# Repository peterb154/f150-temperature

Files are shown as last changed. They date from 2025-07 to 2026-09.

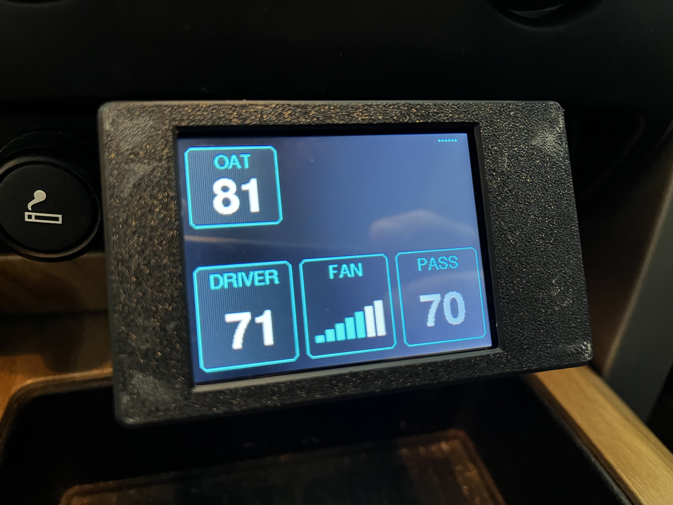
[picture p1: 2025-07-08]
docs/IMG_2838.HEIC.jpg

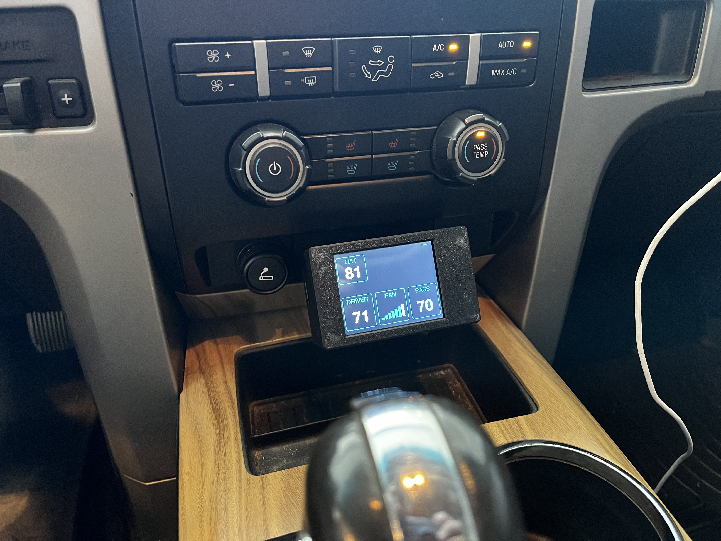
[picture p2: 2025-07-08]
docs/IMG_2837.HEIC.jpg

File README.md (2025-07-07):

# Ford F150 Temperature Display System

A production-ready Ford F150 temperature display system using ESP32-S3 with CAN bus integration and TFT display. This project provides a clean, automotive-grade interface showing outside air temperature, HVAC driver/passenger temperature settings, and fan speed with pixel-perfect text centering and professional styling.

## 🚗 Project Overview

This system captures and displays real-time Ford F150 climate control data via CAN bus at 125 kbps. It features a modern 4-card layout optimized for readability and includes special handling for HVAC off states, simulation mode for testing, and optional CSV logging for data analysis.

### Key Features

- **Real-time Temperature Display** - OAT, driver/passenger HVAC temps, and fan speed
- **Professional UI** - 4-card layout with pixel-perfect text centering and TrueType fonts
- **HVAC State Handling** - Blank display for disabled/off climate controls
- **Simulation Mode** - Built-in test mode cycling through various temperature scenarios
- **Adaptive Backlight** - PWM brightness control based on console dimming level
- **Optional CSV Logging** - Data capture for serial visualization tools (toggleable)
- **Parameterized Design** - Easy customization of fonts, colors, and layout

## 📁 Project Structure

```text
.
├── src/
│   ├── main.cpp                  # Production temperature display system
│   └── main.cpp.save.logger      # Original CAN logger (backup)
├── include/
│   ├── pins.h                    # Hardware pin assignments
│   └── colors.h                  # TFT display color definitions
├── can_visual_grid.py            # Python visualization tool (legacy)
├── F150_*.md                     # Decoded system documentation
│   ├── F150_CONSOLE_LIGHTS.md
│   ├── F150_HVAC_FAN.md
│   ├── F150_HVAC_TEMP.md
│   └── F150_OAT.md
├── platformio.ini                # ESP32 build configuration
├── pyproject.toml               # Python dependencies (for analysis tools)
└── README.md                    # This documentation
```

## 🔧 Hardware Requirements

### ESP32 Temperature Display Setup

- **ESP32-S3 Development Board** (320KB RAM, 8MB Flash recommended)
- **CAN Transceiver Module** (WCMCU-230 or MCP2551)
- **ILI9341 TFT Display** (320x240, SPI interface)
- **XPT2046 Touch Controller** (optional, for future expansion)

### Pin Configuration

Pin assignments are defined in `include/pins.h`:

```cpp
// CAN Bus pins
#define CAN_TX_PIN 47
#define CAN_RX_PIN 48

// ILI9341 Display pins
#define TFT_CS   45
#define TFT_RST  0
#define TFT_DC   35
#define TFT_MOSI 36
#define TFT_CLK  37
#define TFT_LED  38  // Backlight control
#define TFT_MISO 39

// Touch Controller pins (XPT2046)
#define TOUCH_CLK  40
#define TOUCH_CS   41
#define TOUCH_DIN  42
#define TOUCH_DO   2
#define TOUCH_IRQ  1

// Status LED
#define STATUS_LED_PIN 15
```

### Vehicle Connection

- **CAN High**: Connect to vehicle's CAN H line (used connection to car stereo)
- **CAN Low**: Connect to vehicle's CAN L line (used connection to car stereo)
- **Ground**: Connect to vehicle chassis ground
- **Power**: 12V from vehicle (with appropriate regulation to 3.3V/5V)

⚠️ **Important**: Use proper CAN bus termination and isolation, the MCU-230 has a built-in termination resistor. Always test on a non-critical vehicle first.

## 💻 Software Setup

### ESP32 Temperature Display Firmware

1. **Clone the repository** and navigate to the project directory
2. **Install PlatformIO** (if not already installed)
3. **Build and upload** the temperature display firmware:

    ```bash
    # Upload to ESP32-S3
    pio run --target upload

    # Monitor serial output (optional)
    pio device monitor
    ```

4. **Connect hardware** according to pin configuration above
5. **Power on** - the system will auto-start in simulation mode for testing
6. **Connect to vehicle CAN bus** to see live temperature data

### Main System Components

#### `src/main.cpp` - Temperature Display System

The main firmware provides a production-ready Ford F150 temperature display with:

- **4-Card Layout**: OAT (top-left), Driver Temp, Fan Speed, Passenger Temp (bottom row)
- **CAN Bus Integration**: Decodes Ford F150 PIDs at 125 kbps
  - `0x3C4` - Outside Air Temperature (bytes 6-7)
  - `0x3C8` - HVAC Driver/Passenger Temps (ASCII encoded, bytes 0-3)
  - `0x357` - Fan Speed (7 levels, byte 1)
  - `0x3B3` - Console Dim Level (PWM backlight control, byte 3)
- **Smart Display Logic**: Blank temperatures when HVAC is off/disabled
- **Adaptive Backlight**: PWM brightness based on console dimming
- **Simulation Mode**: Built-in test scenarios for development/demo

#### `include/pins.h` - Hardware Configuration

Centralized pin assignments for ESP32-S3 connections.

#### `include/colors.h` - Display Theme

Defines the professional color scheme using 16-bit RGB565 format:

- **COLOR_BACKGROUND** (`0x0841`) - Dark blue-grey background
- **COLOR_CARD_BG** (`0x2124`) - Lighter grey for temperature cards
- **COLOR_PRIMARY** (`0x07FF`) - Cyan accent color
- **COLOR_TEXT** (`0xFFFF`) - White text
- **COLOR_SUCCESS/WARNING/HOT** - Status and temperature-based colors

Colors can be easily customized by modifying the hex values in this file.

## 📊 System Features

### Temperature Display Layout

**4-Card Professional Interface:**
- **OAT Card** (top-left): Outside Air Temperature with "OAT" label
- **DRIVER Card** (bottom-left): Driver HVAC temperature setting
- **FAN Card** (bottom-center): Visual fan speed bars (7 levels)
- **PASS Card** (bottom-right): Passenger HVAC temperature setting

### Smart Display Features

- **Pixel-Perfect Centering**: All temperature values are precisely centered using TrueType fonts
- **Blank State Handling**: Cards show blank when HVAC is off or controls are disabled
- **Adaptive Backlight**: Display brightness automatically adjusts based on console dimming
- **Professional Styling**: Rounded cards, consistent spacing, automotive-grade appearance

### HVAC State Detection

- **HVAC Off**: When driver temp is 0x00,0x00, display shows blank and fan speed goes to 0
- **Passenger Disabled**: Passenger temp shows blank when controls are disabled
- **Normal Operation**: All temperatures display with clean numeric values (no "F" suffix)
- **Fan Visualization**: Horizontal bars indicate fan speed levels 0-7

### Simulation Mode

**Built-in Test Scenarios** (6-second cycles):
1. **Normal Operation** - All temps active, fan running
2. **HVAC System Off** - Driver blank, fan 0, passenger may be active
3. **Passenger Disabled** - Passenger blank, driver/fan normal
4. **All HVAC Off** - Both temps blank, fan 0
5. **Mixed States** - Various combinations for testing

### Optional CSV Logging

**Data Capture for Analysis:**
- **Toggle Control**: Set `enableCSVLogging = true` in code
- **CSV Format**: Timestamp, CAN ID, raw bytes, decoded temperatures
- **Serial Output**: Compatible with visualization tools
- **Performance**: Minimal overhead when enabled, zero when disabled

## 🔍 CAN Bus Analysis Tools

For reverse-engineering additional Ford F150 systems and analyzing CAN bus data, see the comprehensive analysis tools documentation:

**[CAN_ANALYSIS_README.md](CAN_ANALYSIS_README.md)**

Includes:
- Interactive CAN message visualization (`can_visual_grid.py`)
- Raw CAN logger firmware
- Complete reverse-engineering workflow
- Decoded system documentation
- Temperature calibration tools

## 🛠️ Usage

### Normal Operation

1. **Power On**: System starts automatically and shows simulation data
2. **Connect to Vehicle**: CAN bus connection switches to live data
3. **Display Updates**: Temperature cards update in real-time (10Hz refresh)
4. **Backlight Control**: Display brightness adapts to console dimming

### Configuration Options

**CSV Logging** (in `main.cpp`):

```cpp
bool enableCSVLogging = false;  // Set to true for data capture
```

**Simulation Mode** (forced during development):

```cpp
bool forceSimulation = true;   // Set to false for vehicle connection
```

### Hardware Customization

- **Pin Assignments**: Modify `include/pins.h` for different ESP32 boards
- **Display Colors**: Customize `include/colors.h` for different themes
- **Card Layout**: Adjust constants at top of `main.cpp` for sizing/positioning

## 🛠️ Troubleshooting

### Display Issues

**Blank or corrupted display:**

- Check SPI connections to ILI9341 (see `pins.h`)
- Verify power supply stability (3.3V/5V)
- Ensure correct pin definitions match your hardware

**No temperature updates:**

- Verify vehicle is running (systems sleep when off)
- Check CAN H/L connections and polarity
- Monitor serial output for CAN message reception
- Try simulation mode first (`forceSimulation = true`)

**Backlight not working:**

- Check TFT_LED pin connection (see `pins.h`)
- Verify PWM output is functioning
- Test with manual brightness setting

### Performance Issues

**Slow or flickering display:**

- Check power supply current capacity
- Verify SPI clock speed settings
- Monitor for memory issues in serial output

**CAN bus connection problems:**

- Ensure 125 kbps baud rate
- Verify CAN transceiver (MCU-230 recommended)
- Check termination resistance (120Ω)

### Development Tips

1. **Start with simulation mode** - validates display without vehicle
2. **Monitor serial output** - shows CAN status and decoded values
3. **Use CSV logging** - captures data for offline analysis
4. **Test incrementally** - verify each system (display, CAN, decoding) separately

## 🤝 License

MIT License

---

## Ready for your F150 dashboard! 🚗📊

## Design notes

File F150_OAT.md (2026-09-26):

# Ford F150 Outside Air Temperature Decoding

## 📍 CAN Message Location

- **PID**: `0x3C4`
- **Outside Air Temperature**: Bytes 6 & 7 (Big Endian)
- **Primary Byte**: Byte 6 (whole °C + 128)
- **Secondary Byte**: Byte 7, top 2 bits (quarter degrees C)

## 🌡️ Decoding Formula (Celsius Method)

```cpp
// 10-bit value: byte6 is whole degrees, top 2 bits of byte7 are quarters
int raw = (byte6 << 2) | (byte7 >> 6);
temperature_c = raw / 4.0 - 128;
temperature_f = (temperature_c * 1.8) + 32;
```

Example: `A1 B8` → raw 646 → 33.5°C → 92.3°F

## 🔬 Engineering Details

Encoding: Celsius-based with 128 decimal offset
Resolution: 0.25°C (byte6 + top 2 bits of byte7)
Range: -128°C to +127°C (-198°F to +261°F)
Practical Range: Covers all automotive conditions

## 📊 Tested Temperature Range

Tested: 34°F to 124°F (1°C to 51°C)
Accuracy: ±2-3°F average error

| Byte6 | Byte7 | Celsius | Fahrenheit | Notes |
|---|---|---|---|---|
| 0x83  | 0x38  | 3°C | 37°F | Cold |
| 0x91  | 0x78  | 17°C | 63°F | Mild |
| 0xA4  | 0x78  | 36°C | 97°F | Hot |
| 0xB1  | 0x38  | 49°C | 120°F | Very Hot |

## 🚗 Implementation Notes

Works for 2011+ F150 with outside air temperature display
Byte 6 is the primary temperature indicator
Formula follows Ford's automotive Celsius encoding standard
Update rate: Real-time with temperature changes

## 🔥 Engine Heat Damping

The raw sensor is accurate at speed but heat-soaks when slow or stopped
(captured: 87.3°F → 92.3°F in 10 s after stopping, actual 88°F). The truck
does not broadcast a filtered OAT, so the display damps it:

- **Above 20 mph for 30 s** (speed from `0x423`, see `F150_SPEED.md`): show the raw reading
- **Otherwise**: the display can only drop — engine heat only biases the sensor high
- **Boot**: the first reading is shown as-is (may read high if heat-soaked, like the factory dash)

## 🔒 Display Hysteresis

Damping stops the *value* drifting, but the shown whole degree still flickered at
speed: sensor resolution is 0.45°F, so a reading parked near a half-degree
boundary crossed it on one quantisation step and the display alternated between
two numbers (#7).

The displayed degree now carries a dead band — it only moves once the reading
clears it by `OAT_HYSTERESIS_F` (0.7°F), which is more than one sensor step:

```cpp
long displayedOAT(float raw, long shown, float hysteresis);  // include/oat_logic.h
```

Shown 72 changes to 73 at 72.7 and to 71 at 71.3, so real movement still tracks
while dither does not. Unit tested in `test/test_oat_logic/`.

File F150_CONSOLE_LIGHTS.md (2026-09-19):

# Ford F150 Console Lights Dimming Decoding

## 📍 CAN Message Location

- **PID**: `0x3B3`
- **Console Dimming**: Byte 3
- **Day/Night Mode**: Byte 0 (`0x00` = day, `0x04` = night)
- **Encoding**: One continuous brightness scale, `0x01`–`0x12` (1–18)

## 💡 Dimming Level Values

The dash light sensor switches between day and night mode. Each mode uses a
different slice of the same scale:

| Mode  | Byte0  | Byte2  | Byte3 (dimmer low → high) | Steps |
|---|---|---|---|---|
| Day | `0x00` | `0x05` | `0x0D` → `0x12` | 6 |
| Night | `0x04` | `0x04` | `0x01` → `0x0C` | 12 |

Example frames (captured 2026-09-18):

```text
day   full high: 00 43 05 12 00 00 00 38
day   full low:  00 43 05 0D 00 00 00 38
night full high: 04 83 04 0C 00 00 00 38
night full low:  04 83 04 01 00 00 00 38
```

Byte 1 toggles between `0x40`/`0x43` (day) and `0x80`/`0x83` (night); not used.

## 🧮 Decoding

```cpp
// Byte 3 is the brightness level directly; anything else is unknown
if (byte3 >= 0x01 && byte3 <= 0x12) {
    dim_level = byte3;  // 1-18
}
```

## 🚗 Implementation Notes

- Works for 2011+ F150 with console dimming controls
- Update rate: ~1 Hz, plus immediately on dimmer change
- Unknown values are ignored so the display keeps its last brightness
- Backlight PWM never drops below `MIN_BACKLIGHT_PWM` so the display is always readable
- Early versions only mapped the day range (`0x0D`–`0x12`), which blanked the display in night mode (#1)

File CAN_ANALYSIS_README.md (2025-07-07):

# 🔍 Ford F150 CAN Bus Analysis Tools

This directory contains tools for analyzing and reverse-engineering Ford F150 CAN bus messages. These tools complement the production temperature display system and are useful for discovering new PIDs and decoding protocols.

## 🛠️ Analysis Tools

### `can_visual_grid.py` - Interactive CAN Message Analyzer

A Python-based real-time CAN message visualization tool that displays messages in a grid format for pattern analysis and reverse engineering.

**Features:**
- **Real-time Display**: Live CAN message visualization with color-coded changes
- **Dual View Modes**: HEX (default) and ASCII modes for different analysis needs
- **Cell Selection**: Click up to 2 cells for detailed analysis and correlation
- **Temperature Calibration**: Built-in calibration mode for temperature sensor discovery
- **Pattern Detection**: Color coding highlights recent changes and printable ASCII

### `main.cpp.save.logger` - Raw CAN Logger

ESP32 firmware that captures raw CAN messages and outputs them via serial for analysis tools.

**Output Format:**
```
TIMESTAMP_MS,ELAPSED_MS,CAN_ID,LENGTH,BYTE0,BYTE1,BYTE2,BYTE3,BYTE4,BYTE5,BYTE6,BYTE7,EXTENDED
```

## 🎮 Using the Visual Grid Monitor

### Setup and Launch

1. **Upload Logger Firmware**:
   ```bash
   # Use the logger version (not the display system)
   cp src/main.cpp.save.logger src/main.cpp
   pio run --target upload
   pio device monitor  # Verify CAN messages are being received
   ```

2. **Install Python Dependencies**:
   ```bash
   pip install pygame numpy
   ```

3. **Launch Analysis Tool**:
   ```bash
   python can_visual_grid.py /dev/cu.wchusbserial56910252611
   # Replace with your ESP32's serial port
   ```

### Display Modes

- **HEX Mode**: Shows raw hexadecimal values (default)
- **ASCII Mode**: Shows ASCII characters, highlights printable text
- **Toggle**: Press `A` to switch between modes

### Cell Selection and Analysis

1. **Click cells** to select up to 2 for analysis
2. **Purple cell**: First selection
3. **Cyan cell**: Second selection
4. **Information panel**: Shows ASCII interpretation and temperature calculations

### Color Coding

- **Bright Green**: Recent changes (< 0.5 seconds)
- **Green**: Recent changes (< 1 second)
- **Yellow**: Somewhat recent (< 2 seconds)
- **Light Green**: Printable ASCII characters (ASCII mode only)
- **White**: No recent changes

### Temperature Calibration Mode

1. **Select temperature sensor cells** (e.g., PID 0x3C4, bytes 6&7)
2. **Press `T`** to enter calibration mode
3. **Adjust vehicle controls** and input actual LCD readings when prompted
4. **Press `T` again** to exit and calculate linear regression formula

### Keyboard Controls

- `A` - Toggle ASCII/HEX display mode
- `T` - Toggle temperature calibration mode
- `C` - Clear cell selection
- `↑↓` - Scroll through PIDs
- `ESC` - Exit application

Send `x` via serial console to insert markers for correlating data with specific actions (e.g., "start HVAC adjustment").

## 📊 Decoded Systems

This project has successfully reverse-engineered several F150 systems. Each system is documented in dedicated markdown files with complete decoding formulas:

- [F150_HVAC_TEMP.md](F150_HVAC_TEMP.md)
- [F150_HVAC_FAN.md](F150_HVAC_FAN.md)
- [F150_OAT.md](F150_OAT.md)
- [F150_CONSOLE_LIGHTS.md](F150_CONSOLE_LIGHTS.md)

## 🔧 Development Workflow

### 1. Data Capture Phase

```bash
# Start ESP32 logger
pio run -t upload

# Capture specific system in Python
python can_visual_grid.py /dev/ttyUSB0
```

### 2. ASCII Discovery Phase

- Switch to ASCII mode (`A` key)
- Look for green-highlighted printable characters
- Select suspicious byte pairs for analysis
- Ford often uses ASCII digits for human-readable values

### 3. Pattern Analysis

- Select 1-2 cells showing interesting patterns
- Use calibration mode for temperature sensors
- Correlate changes with vehicle control adjustments
- Document findings in new markdown files

### 4. Validation

- Test discovered formulas across temperature ranges
- Cross-reference with multiple data capture sessions
- Document edge cases and special states

### 5. Integration

- Add new decoders to the production temperature display system
- Update `main.cpp` with new PID handlers
- Test real-time display functionality

## 🚗 Known Ford F150 PIDs

### Temperature Systems
- **0x3C4** - Outside Air Temperature (bytes 6-7, Celsius + 40 offset)
- **0x3C8** - HVAC Driver/Passenger Temps (ASCII encoded, bytes 0-3)

### HVAC Controls  
- **0x357** - Fan Speed (7 levels, byte 1)
- **0x3B3** - Console Dim Level (PWM brightness, byte 3)

### Additional Systems

- Various engine, transmission, and body control PIDs documented in individual markdown files

## 💡 Analysis Tips

1. **Start with ASCII Mode**: Many Ford systems use human-readable ASCII encoding
2. **Look for Patterns**: Temperature values often follow predictable mathematical relationships
3. **Use Multiple Test Points**: Capture data across full range of values for accurate formulas
4. **Cross-Reference**: Compare findings with known automotive protocols and standards
5. **Document Everything**: Include test conditions, vehicle state, and environmental factors

## 🔄 Switching Back to Temperature Display

To return to the production temperature display system:

```bash
# Restore the display firmware
cp src/main.cpp.save.logger src/main.cpp.bak  # backup logger
git checkout src/main.cpp  # restore display system
pio run --target upload
```

The analysis tools and production display system are designed to work together - use the analysis tools to discover new data, then integrate findings into the display system for real-time monitoring.

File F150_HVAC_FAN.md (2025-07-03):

# Ford F150 HVAC Fan Speed Decoding

## 📍 CAN Message Location

- **PID**: `0x357`
- **Fan Speed**: Byte 3
- **Encoding**: Direct value mapping (7 discrete levels)

## 🌪️ Fan Speed Values

```cpp
// Direct byte value to fan speed mapping
switch(byte3) {
   case 0x1C: return "HIGH (Level 7)";
   case 0x18: return "Level 6";
   case 0x14: return "Level 5";
   case 0x10: return "Level 4";
   case 0x0C: return "Level 3";
   case 0x08: return "Level 2";
   case 0x04: return "LOW (Level 1)";
   default:   return "OFF or Unknown";
}
```

| Byte3 Value | Fan Level | Description |
|---|---|---|
| 0x1C | 7 | HIGH (Maximum airflow) |
| 0x18 | 6 | High-medium |
| 0x14 | 5 | Medium-high |
| 0x10 | 4 | Medium |
| 0x0C | 3 | Medium-low |
| 0x08 | 2 | Low-medium |
| 0x04 | 1 | LOW (Minimum airflow) |
| Other | 0 | OFF or Unknown |

## 🔬 Engineering Details

- Encoding: Simple descending 4-bit pattern
- Resolution: 7 discrete fan speeds
- Pattern: Each level decreases by 0x04 (4 decimal)
- Range: 0x04 to 0x1C (4 to 28 decimal)

## 🧮 Alternative Formula
```cpp// Calculate fan level from byte value
if (byte3 >= 0x04 && byte3 <= 0x1C && (byte3 % 4) == 0) {
    fan_level = (byte3 / 4);  // Results in 1-7
} else {
    fan_level = 0;  // OFF or invalid
}
```

## 🚗 Implementation Notes

Works for 2011+ F150 with manual or automatic HVAC controls
Update rate: Real-time with fan speed adjustment
Simple linear encoding makes this easy to decode
Pattern: Each fan level = previous level + 4

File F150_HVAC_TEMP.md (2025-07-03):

# Ford F150 HVAC Temperature Setpoint Decoding

## 📍 CAN Message Location

- **PID**: `0x3C8`
- **Driver Temperature**: Bytes 0 & 1
- **Passenger Temperature**: Bytes 2 & 3

## 🧮 Decoding Formula (ASCII Method)

```cpp
// Ford encodes position as ASCII decimal digits!
// Example: 0x37, 0x35 = ASCII "75" = position 75

// Convert bytes to ASCII characters
char tens_digit = (char)byte0;  // '6', '7', '8', '9'
char ones_digit = (char)byte1;  // '0' through '9'

// Build position string and convert to integer
char position_str[3] = {tens_digit, ones_digit, '\0'};
int position = atoi(position_str);  // "75" -> 75

// Map position to temperature
if (position == 60) {
    return "LOW";
} else if (position == 90) {
    return "HIGH"; 
} else if (position >= 65 && position <= 84) {
    int temp_f = position - 5;  // 65->60°F, 75->70°F, etc.
    return temp_f;
} else {
    return "UNKNOWN";
}
```

## 🔤 ASCII Encoding Details

- **Byte0 Range**: 0x36-0x39 = ASCII '6'-'9' (tens digit)
- **Byte1 Range**: 0x30-0x39 = ASCII '0'-'9' (ones digit)
- **Position Range**: "60" to "90" (ASCII decimal)
- **Ford's Logic**: Direct ASCII decimal encoding for easy diagnostics

## 📊 Temperature Ranges

- **LOW**: Position 60 (Below 60°F)
- **Normal Range**: 60-83°F (positions 65-84)
- **HIGH**: Position 90 (Above 83°F)
- **Resolution**: 1°F per step

## 🎯 Example Values

| Byte0 | Byte1 | ASCII | Position | Result |
|---|---|---|---|---|
| 0x36  | 0x30  | "60"  | 60 | LOW |
| 0x36  | 0x35  | "65"  | 65 | 60°F |
| 0x37  | 0x30  | "70"  | 70 | 65°F |
| 0x37  | 0x35  | "75"  | 75 | 70°F |
| 0x38  | 0x34  | "84"  | 84 | 79°F |
| 0x39  | 0x30  | "90"  | 90 | HIGH |

## 🚗 Implementation Notes

- Both driver and passenger use identical ASCII encoding
- Formula works for 2011+ F150 with dual-zone HVAC
- Update rate: Real-time with HVAC knob adjustments
- Celsius conversion: `temp_c = (temp_f - 32) * 5/9`
- **Key Insight**: Ford uses ASCII digits for human-readable diagnostics
- HVAC OFF: Driver temps will be zero (0x3C8 b0 = 0x00 & b1 = 0x00)
- PASS TEMP OFF: Pass temps will be zero (0x3C8 b2 = 0x00 & b3 = 0x00)
- LOW == 60°F
- HIGH == 85°F, then next click jumps to 90°F

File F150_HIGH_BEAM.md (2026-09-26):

# Ford F150 High Beam Decoding

## 📍 CAN Message Location

- **PID**: `0x3C3`
- **High Beam**: Byte 0, bit 1 (mask `0x02`)
- **Headlamps**: Byte 0, bits 7 / 4 — set together as `0x90` when lights are on

## 🧮 Decoding

```cpp
bool highBeamOn = (byte0 & 0x02) != 0;
```

## 📊 Observed Byte 0 Values (captured 2026-09-26)

| Byte0  | Headlamps | High beam |
|---|---|---|
| `0x00` | off | off |
| `0x02` | off | **on** |
| `0x90` | on | off |
| `0x92` | on | **on** |

Byte 1 bit 5 is the inverse of the same state (`0x21` → `0x01` on high beam) and is
not used.

## ✅ Verification

Two independent captures, analysed by diffing every byte of every ID:

- **Five toggles**: bit 1 went high at 14.9, 17.1, 18.8, 20.5 and 22.2 s — exactly
  five pulses, no other byte on the bus matched
- **Single flip, held**: bit 1 low until 10.8 s, then high for 72 s continuously

## 🚗 Implementation Notes

- Update rate: ~1 Hz, plus immediately on change (same pattern as `0x3B3`)
- **There is no separate flash-to-pass on this truck** — flashing is cycling the
  high beams, so it is the same bit by construction and cannot be distinguished
- Measured toggle durations were **1.0–1.7 s**, so the flood-arm delay must exceed
  that comfortably; `HIGH_BEAM_ARM_MS` is 2500 ms
- Treat a stale message as high beam **off**: if no `0x3C3` arrives for
  `HIGH_BEAM_STALE_MS`, drop the flood rather than holding the last state

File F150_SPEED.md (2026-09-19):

# Ford F150 Vehicle Speed Decoding

## 📍 CAN Message Location

- **PID**: `0x423`
- **Vehicle Speed**: Bytes 0 & 1 (Big Endian)

## 🧮 Decoding Formula

```cpp
int raw = (byte0 << 8) | byte1;
float kph = (raw - 10000) / 100.0;  // 0.01 km/h per bit, 10000 = stopped
float mph = kph / 1.609;
```

## 📊 Captured Values (2026-09-18)

| Raw | km/h | mph  | Notes |
|---|---|---|---|
| `10000` | 0 | 0 | Stopped |
| `13054` | 30.5 | 19.0 | Accelerating |
| `15070` | 50.7 | 31.5 | Holding an indicated 30 mph |

Reads ~5% above the speedometer; close enough for thresholds.

## 🚗 Implementation Notes

- Update rate: ~10 Hz
- Used to decide when the raw OAT reading can be trusted (see `F150_OAT.md`)

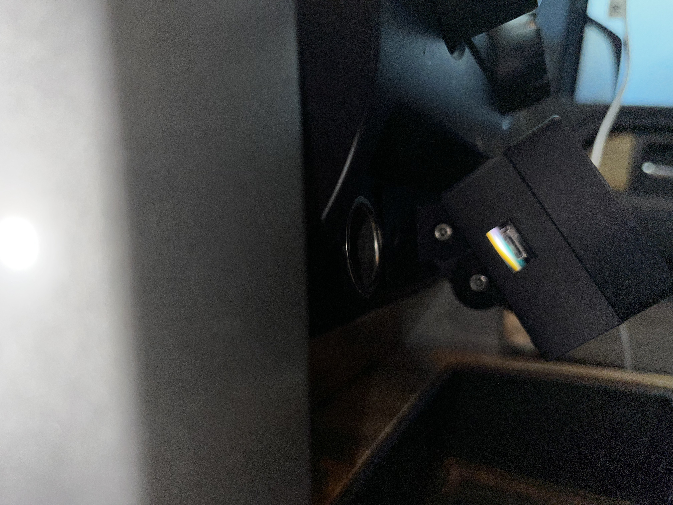
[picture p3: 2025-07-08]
docs/IMG_2835.HEIC.jpg

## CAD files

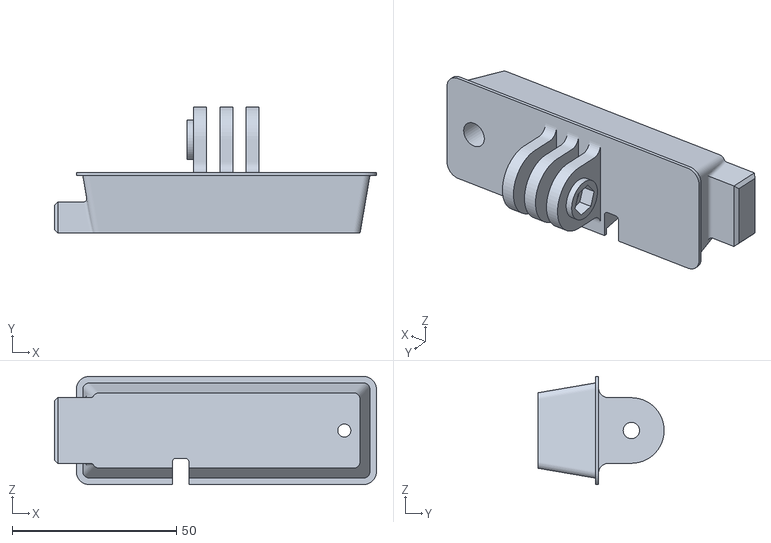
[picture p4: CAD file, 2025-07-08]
case/Truck_mount.stl
98.1 x 38.5 x 33.0

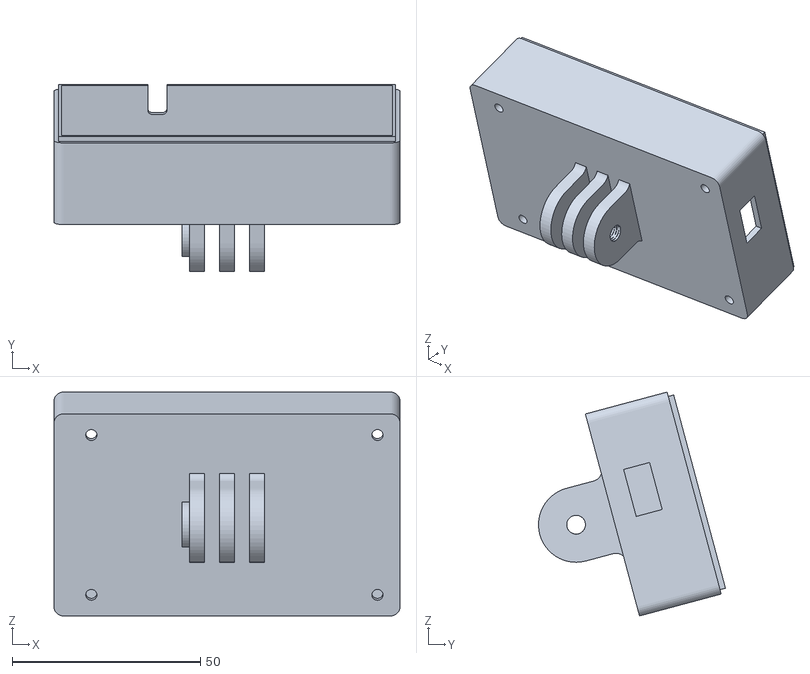
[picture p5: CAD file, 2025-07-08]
case/Screen_back.stl
92.0 x 49.7 x 59.5

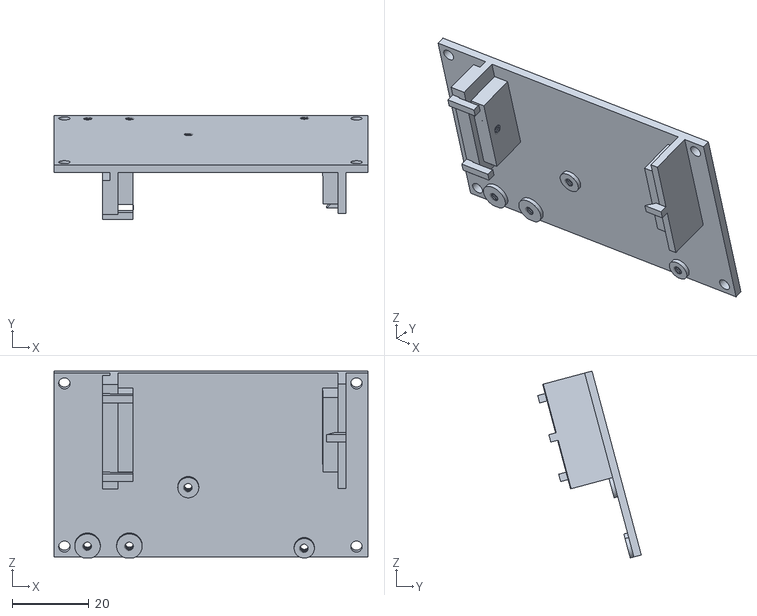
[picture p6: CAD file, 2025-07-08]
case/PartPlate.stl
81.8 x 27.0 x 48.7

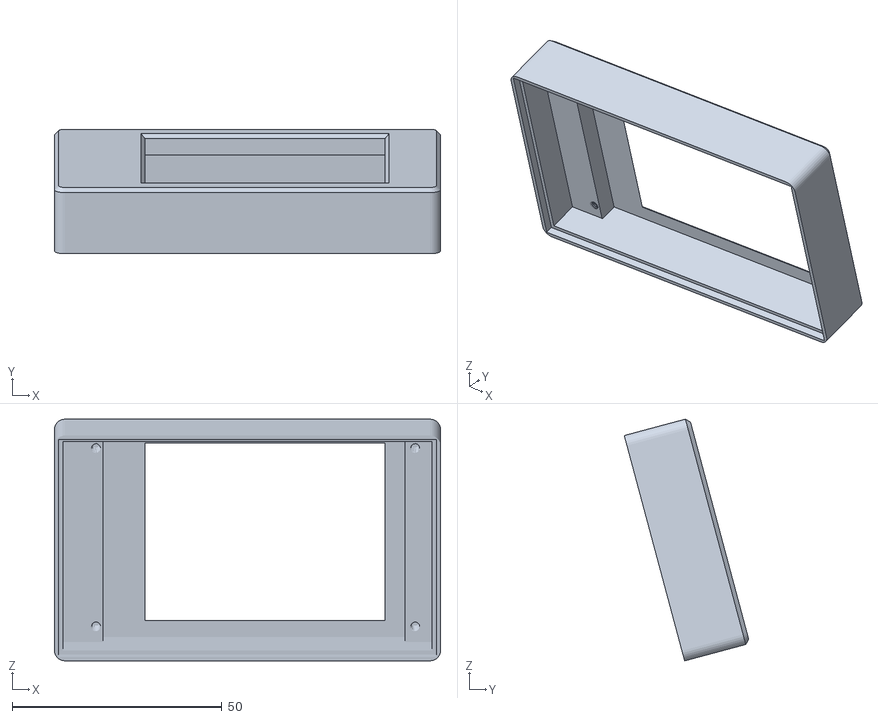
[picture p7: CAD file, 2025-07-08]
case/Screen_case.stl
92.0 x 29.7 x 57.6

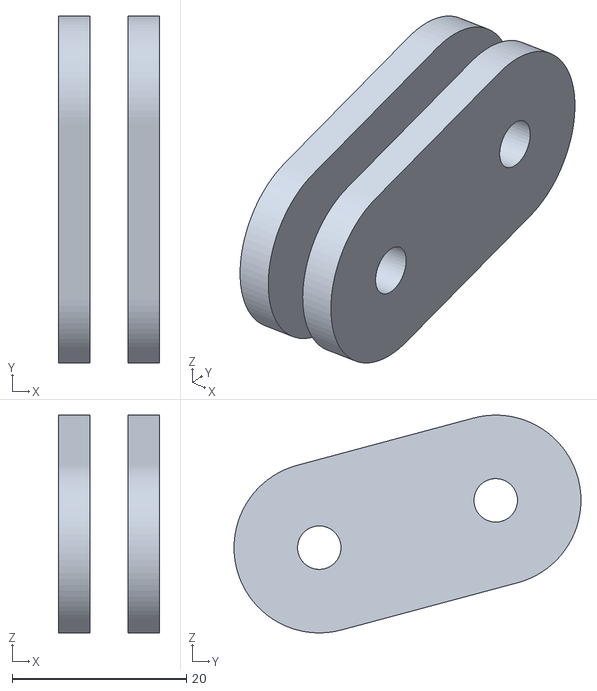
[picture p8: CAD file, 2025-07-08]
case/Arm.stl
11.6 x 39.9 x 25.0

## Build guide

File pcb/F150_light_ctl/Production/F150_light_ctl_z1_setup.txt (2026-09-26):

================================================================
Makera Z1 setup sheet -- F150_light_ctl
================================================================

G-code    F150_light_ctl_z1.ngc
Board     F150_light_ctl.kicad_pcb  (1.60mm thick)
Side      TOP-DOWN -- component side up.
Origin    KiCad drill/place (aux) origin
Extent    X -7.31 to 9.39, Y -11.85 to 3.35 mm
Depth     1.80mm  (1.60 board + 0.20 breakthrough)
Spindle   13000 rpm

TOOLS, in program order
----------------------------------------------------------------
  T1     0.80 mm  CORN/FISHTAIL END MILL     5 hole(s), every size with this one bit, milled helically
  T2     1.20 mm  CORN/FISHTAIL END MILL     outline 62.8mm, 1 path(s), 4 tab(s) of 1.00mm at Z-1.00

You will be asked to install:
----------------------------------------------------------------
  T1   0.80mm CORN/FISHTAIL END MILL (NOT a twist drill)
  T2   1.20mm CORN/FISHTAIL END MILL (NOT a twist drill)

BEFORE YOU START
----------------------------------------------------------------
  * USE A SACRIFICIAL LAYER. Cuts go ~0.2mm past the far face.
  * Install T1, then Tool dropdown -> Change tool -> T1
    (registers the tool and sets its TLO).
  * Set XY origin to the drill/place origin. Do not move it again.
  * Run the first tool with Auto Z Probe ON. Z0 is tool-independent,
    so later tools need no re-probe -- the M6 re-zeros them on the
    back-right setter.

DURING THE RUN
----------------------------------------------------------------
  * Each M6 stops and prompts for the swap, then re-zeros on the
    setter. Do not skip the re-zero.
  * The outline is cut LAST: it is what frees the part. It stays
    held by 4 tab(s) of 1.00mm until you snap them.

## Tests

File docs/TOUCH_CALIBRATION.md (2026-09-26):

# Touch Calibration

The XPT2046 reports raw 12-bit ADC values, not pixels. Mapping them to the
screen needs the raw value at each edge of the panel, stored as `TOUCH_CAL_*`
in `include/touch_logic.h`.

## Why this has its own procedure

Getting the range wrong is **invisible in the middle of the screen**. A linear
map with symmetric endpoint errors is still exactly right at the centre, so a
centre press proves nothing. The error only appears at the edges, where presses
clamp and silently miss whatever is there.

That is how #9 survived: `TOUCH_CAL_MAXY` was 2830 against a real 3402, so every
press on the top of the screen clamped to `sy = 0` and missed a button starting
at `y = 10`. It looked like unreliable touch hardware for an entire session.

**Measure the edges. Never extrapolate them.**

## Procedure

1. Flash the bring-up harness:

   ```bash
   pio run -e floodtest -t upload --upload-port /dev/cu.usbmodem*
   ```

2. Open a serial monitor at 115200 (`pio device monitor -e floodtest`).

3. Press firmly into **all four edges** of the glass, right at the bezel — top,
   bottom, left, right. Drag along each edge to be sure you reach the extremes.
   The harness tracks the running minimum and maximum as you go.

4. Send `c`. It prints the four constants ready to paste:

   ```
   #define TOUCH_CAL_MINX 780
   #define TOUCH_CAL_MAXX 3298
   #define TOUCH_CAL_MINY 858
   #define TOUCH_CAL_MAXY 3402
   ```

   Send `r` to start over if you want a clean run.

5. Paste them into `include/touch_logic.h`.

6. Run the host tests — they share those constants, so they will tell you if a
   known-good press no longer lands on the button:

   ```bash
   pio test -e native
   ```

7. Reflash the display firmware:

   ```bash
   pio run -e esp32s3 -t upload --upload-port /dev/cu.usbmodem*
   ```

## Notes

- Both axes run **opposite** to the display: a low raw value is the bottom/right
  of the screen, a high one is the top/left. `touch_logic.h` handles the
  inversion; the constants are plain observed minima and maxima.
- A finger has width, so pressing "the edge" lands slightly inside it. Erring a
  little wide is harmless — mapped values are clamped.
- The harness also toggles the flood relay (`1`, `0`, `p`), which is the only
  way to control the light bar if the touchscreen is unavailable.

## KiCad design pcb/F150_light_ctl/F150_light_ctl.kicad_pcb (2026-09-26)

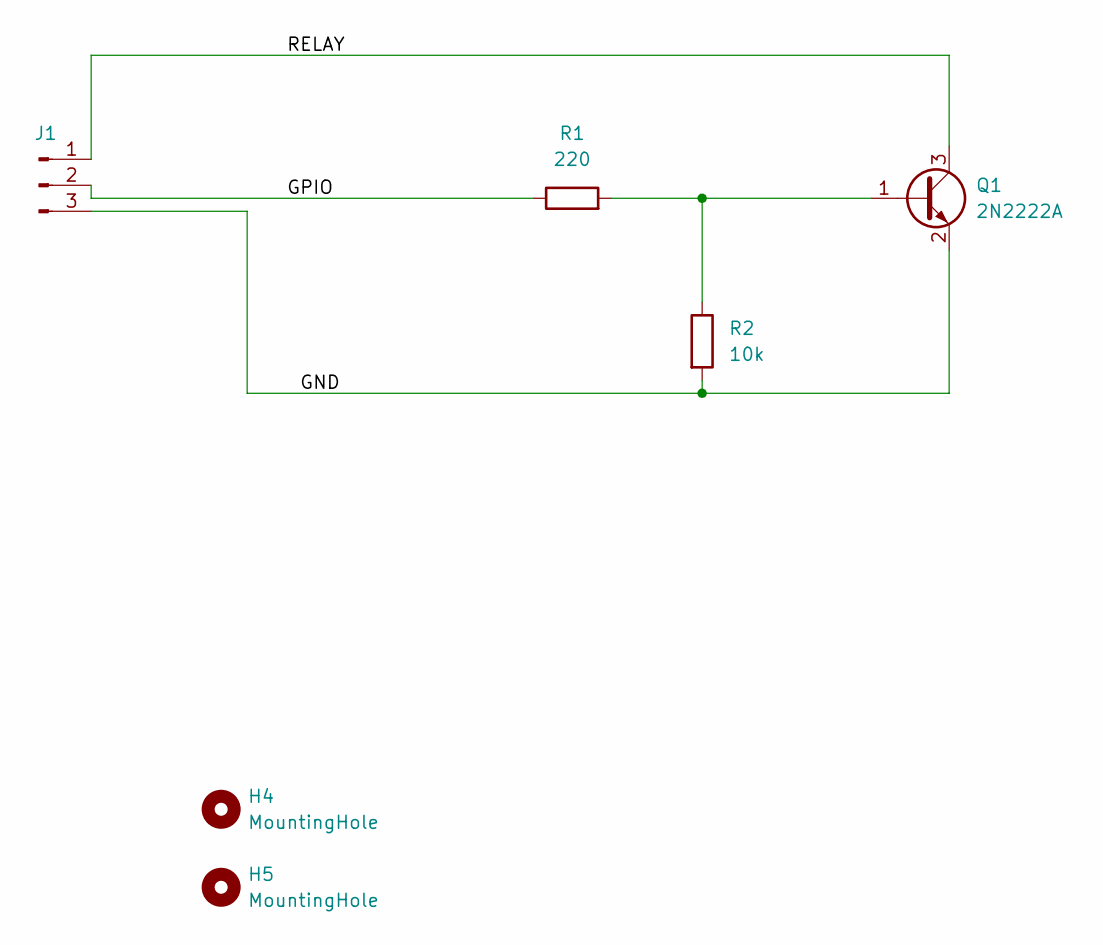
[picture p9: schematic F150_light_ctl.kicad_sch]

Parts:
H4, H5: MountingHole; MountingHole_3.5mm
J1: PinHeader_1x03_P2.54mm_Vertical
Q1: 2N2222A; SOT-23
R1: 220; R_0805_2012Metric
R2: 10k; R_0805_2012Metric

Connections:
/GND: J1.3, Q1.2 (E), R2.2
/GPIO: J1.2, R1.1
/RELAY: J1.1, Q1.3 (C)
unnamed: Q1.1 (B), R1.2, R2.1

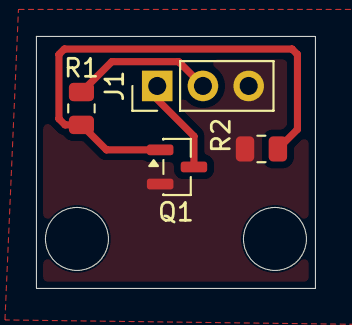
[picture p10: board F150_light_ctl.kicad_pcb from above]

Board: 2 copper layers, 15.5 x 14.0 mm, 6 parts (0 on the bottom side), 4 nets.

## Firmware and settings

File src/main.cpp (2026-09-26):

#include <Arduino.h>
#include <SPI.h>
#include <pins.h>
#include <colors.h>
#include <Adafruit_GFX.h>
#include <Adafruit_ILI9341.h>
#include <driver/twai.h>
#include <XPT2046_Touchscreen.h>
#include <Preferences.h>
#include <flood_logic.h>
#include <oat_logic.h>
#include <touch_logic.h>
#include <stdint.h>
#include <Fonts/FreeSans9pt7b.h>
#include <Fonts/FreeSansBold12pt7b.h>
#include <Fonts/FreeSansBold18pt7b.h>
#include <Fonts/FreeSansBold24pt7b.h>

// ========== LAYOUT PARAMETERS ==========
// Card dimensions and spacing
#define CARD_WIDTH 95
#define CARD_HEIGHT 100
#define CARD_RADIUS 6
#define CARD_SPACING 10

// OAT card (smaller, top-left)
#define OAT_WIDTH 90
#define OAT_HEIGHT 80
#define OAT_X 10
#define OAT_Y 10

// Bottom row cards
#define BOTTOM_Y 130
#define DRIVER_X 10
#define FAN_X (DRIVER_X + CARD_WIDTH + CARD_SPACING)
#define PASS_X (FAN_X + CARD_WIDTH + CARD_SPACING)

// Flood light button - top-right grid slot (OAT's row, PASS's column)
#define FLOOD_X PASS_X
#define FLOOD_Y OAT_Y
#define FLOOD_W OAT_WIDTH
#define FLOOD_H OAT_HEIGHT

// Touch calibration lives in include/touch_logic.h so the firmware and the
// host tests share one set of numbers. See docs/TOUCH_CALIBRATION.md to
// re-measure it.
#define TOUCH_HIT_MARGIN 8   // forgiveness around the button edge
#define TOUCH_DEBOUNCE_MS 250

// "OFF" is three wide glyphs; the 24pt value font overflows a 90px card
#define FLOOD_STATE_FONT &FreeSansBold18pt7b

// High beam arming. Measured stalk toggles ran 1.0-1.7 s, and this truck has no
// separate flash-to-pass, so the delay must outlast a flash or the bar strobes
// oncoming traffic. Turning off is immediate; only turning on waits.
#define HIGH_BEAM_MASK      0x02
#define HIGH_BEAM_ARM_MS    2500
#define HIGH_BEAM_STALE_MS  3000   // no 0x3C3 for this long -> assume beams off

// Font sizes
#define LABEL_FONT &FreeSans9pt7b
#define VALUE_FONT &FreeSansBold24pt7b  // Larger font
#define SMALL_FONT &FreeSansBold12pt7b

// Text positioning offsets
#define LABEL_OFFSET_X 10
#define LABEL_OFFSET_Y 20
#define VALUE_OFFSET_X 15
#define VALUE_OFFSET_Y 80  // Adjusted for larger font
#define OAT_VALUE_OFFSET_Y 65  // OAT card is shorter

// F150 CAN Message IDs based on documentation
#define PID_OAT           0x3C4  // Outside Air Temperature
#define PID_HVAC_TEMP     0x3C8  // HVAC Temperature Settings
#define PID_HVAC_FAN      0x357  // HVAC Fan Speed
#define PID_CONSOLE_LIGHTS 0x3B3 // Console Light Dimming
#define PID_VEHICLE_SPEED 0x423  // Vehicle Speed
#define PID_LIGHTING      0x3C3  // Headlamp / high beam (see F150_HIGH_BEAM.md)

// OAT damping: engine heat skews the sensor high when slow or stopped
#define OAT_MOVING_MPH    20     // Above this speed...
#define OAT_MOVING_MS     30000  // ...for this long, trust the raw OAT
// Dead band on the displayed degree. Larger than one 0.45 F sensor step, so
// quantisation noise near a boundary cannot flip the number (see #7).
#define OAT_HYSTERESIS_F  0.7f

// Console dim scale: night mode uses 1-12, day mode uses 13-18
#define NIGHT_MAX_LEVEL    12
#define MAX_DIM_LEVEL      18
#define MIN_BACKLIGHT_PWM  15  // Never fully dark, even at lowest night dimmer
#define NIGHT_MAX_PWM      170
#define DAY_MIN_PWM        60  // Day gets its own range so the dimmer is visible

// Create TFT instance
Adafruit_ILI9341 tft = Adafruit_ILI9341(TFT_CS, TFT_DC, TFT_MOSI, TFT_CLK, TFT_RST, TFT_MISO);
// Polled, not IRQ-driven. In IRQ mode the library sets isrWake=false as soon as
// one sample reads below its pressure threshold, and only a new falling edge
// rearms it - so a soft press is sampled once while the finger is still
// settling, discarded, and never looked at again. With no IRQ pin isrWake stays
// true and update() samples on every call.
//
// Note this was NOT the cause of the missed presses in #9 - that was a bad
// calibration range. The latch is a real defect regardless.
XPT2046_Touchscreen ts(TOUCH_CS);

// Flood light state. Mode is what the button selects; lit is what the pin does.
FloodMode floodMode = FLOOD_OFF;
FloodMode prevFloodMode = FLOOD_ARMED;  // mismatch forces the first draw
bool floodLit = false;
bool prevFloodLit = true;

bool highBeamOn = false;
unsigned long highBeamSince = 0;    // when the beams last came on
unsigned long lastLightingMsg = 0;  // for the stale-bus watchdog
Preferences floodPrefs;

// Display data variables
float outsideTemp = 72.0;     // Outside Air Temperature (°F), damped for display
bool oatSeeded = false;       // First OAT reading is shown as-is
unsigned long movingSince = 0; // millis() when speed went above OAT_MOVING_MPH, 0 = slow
int driverTempSet = 72;       // Driver temperature setting (°F)
int passengerTempSet = 70;    // Passenger temperature setting (°F)
int fanSpeed = 3;             // Fan speed level (0-7)
int consoleDimLevel = MAX_DIM_LEVEL; // Console brightness (1-18)
bool dataReceived = false;

// Previous values for dirty flag checking
long shownOAT = OAT_DISPLAY_UNSET;      // degrees we want on screen
long drawnOAT = OAT_DISPLAY_UNSET - 1;  // what is on screen; mismatch forces first draw
int prevDriverTempSet = -1;
int prevPassengerTempSet = -1;
int prevFanSpeed = -1;

// Display update tracking
unsigned long lastDisplayUpdate = 0;
unsigned long lastSimulationUpdate = 0;

// CSV Logging for serial visualization
// Set enableCSVLogging = true to output CSV data compatible with F150 serial visualizer
// This adds minimal performance overhead and is useful for data analysis
bool enableCSVLogging = false;  // Set to true to enable CSV output
unsigned long sessionStartTime = 0;
unsigned long messageCount = 0;
bool simulationMode = false; // Force simulation for testing

// Function prototypes
void setup();
void loop();
void initDisplay();
void initCAN();
void updateDisplay();
void simulateData();
void processCanMessages();
void drawTempCard(int x, int y, int w, int h, const char* label, int temp);
void drawFanCard(int x, int y, int w, int h, int fanLevel);
void drawOATCard(int x, int y, int w, int h, long temp);
float decodeOAT(uint8_t byte6, uint8_t byte7);
float decodeSpeedMph(uint8_t byte0, uint8_t byte1);
void updateOAT(float rawOAT);
int decodeHVACTemp(uint8_t byte0, uint8_t byte1);
int decodeFanSpeed(uint8_t byte3);
int decodeConsoleDim(uint8_t byte3);
void setBacklightBrightness(int level);
void initTouch();
void handleTouch();
void drawFloodCard(int x, int y, int w, int h, FloodMode mode, bool lit);
void updateFlood();

// Arduino Setup Function
void setup() {
  // Flood light off before anything else can run
  pinMode(FLOOD_PIN, OUTPUT);
  digitalWrite(FLOOD_PIN, LOW);

  Serial.begin(115200);
  
  if (enableCSVLogging) {
    // CSV header for serial visualization tools
    Serial.println("F150_TEMPERATURE_CSV_START");
    Serial.println("TIMESTAMP_MS,ELAPSED_MS,CAN_ID,LENGTH,BYTE0,BYTE1,BYTE2,BYTE3,BYTE4,BYTE5,BYTE6,BYTE7,EXTENDED,OAT_F,DRIVER_TEMP,PASS_TEMP,FAN_SPEED,CONSOLE_DIM");
    sessionStartTime = millis();
  } else {
    Serial.println("F150 Temperature Display Starting...");
  }
  
  // Restore the saved mode. ARM persists because that is the normal setting;
  // ON deliberately does not, so a key-on never fires the bar by itself.
  floodPrefs.begin("flood", false);
  uint8_t savedMode = floodPrefs.getUChar("mode", FLOOD_OFF);
  floodMode = savedMode == FLOOD_ARMED ? FLOOD_ARMED : FLOOD_OFF;

  initDisplay();
  initTouch();
  Serial.printf("Flood mode restored: saved=%u -> %s\n", savedMode,
                floodMode == FLOOD_ARMED ? "ARM" : "OFF");
  initCAN();
  
  if (enableCSVLogging) {
    Serial.println("# CSV logging enabled - compatible with F150 serial visualizer");
  } else {
    Serial.println("Setup complete - starting main loop");
  }
}

// Arduino Main Loop
void loop() {
  handleTouch();
  processCanMessages();
  updateFlood();
  
  if (simulationMode && millis() - lastSimulationUpdate > 2000) {
    simulateData();
    lastSimulationUpdate = millis();
  }
  
  if (millis() - lastDisplayUpdate > 100) {
    updateDisplay();
    lastDisplayUpdate = millis();
  }
  
  delay(10);
}

// Initialize TFT Display
void initDisplay() {
  pinMode(TFT_LED, OUTPUT);
  setBacklightBrightness(consoleDimLevel);
  
  tft.begin();
  tft.setRotation(1);
  tft.fillScreen(COLOR_BACKGROUND);
  
  Serial.println("Display initialized");
}

// Initialize CAN Bus
void initCAN() {
  pinMode(CAN_RX_PIN, INPUT);
  pinMode(CAN_TX_PIN, OUTPUT);
  
  twai_general_config_t g_config = TWAI_GENERAL_CONFIG_DEFAULT((gpio_num_t)CAN_TX_PIN, (gpio_num_t)CAN_RX_PIN, TWAI_MODE_NORMAL);
  twai_timing_config_t t_config = TWAI_TIMING_CONFIG_125KBITS();
  twai_filter_config_t f_config = TWAI_FILTER_CONFIG_ACCEPT_ALL();
  
  if (twai_driver_install(&g_config, &t_config, &f_config) == ESP_OK) {
    Serial.println("CAN driver installed successfully");
  } else {
    Serial.println("Failed to install CAN driver - entering simulation mode");
    simulationMode = true;
    return;
  }
  
  if (twai_start() == ESP_OK) {
    Serial.println("CAN driver started successfully");
    // simulationMode remains as initialized (false for normal operation)
  } else {
    Serial.println("Failed to start CAN driver - entering simulation mode");
    simulationMode = true;
  }
}

// Process CAN Messages
void processCanMessages() {
  if (simulationMode) return;
  
  twai_message_t message;
  while (twai_receive(&message, 0) == ESP_OK) {
    dataReceived = true;
    messageCount++;
    
    // Optional CSV logging for serial visualization
    if (enableCSVLogging) {
      unsigned long timestamp = millis();
      unsigned long elapsed = sessionStartTime > 0 ? timestamp - sessionStartTime : 0;
      
      // CSV format: TIMESTAMP,ELAPSED,CAN_ID,LENGTH,BYTE0-7,EXTENDED,OAT,DRIVER,PASS,FAN,DIM
      Serial.print(timestamp);
      Serial.print(",");
      Serial.print(elapsed);
      Serial.print(",0x");
      Serial.print(message.identifier, HEX);
      Serial.print(",");
      Serial.print(message.data_length_code);
      
      // Output data bytes
      for (int i = 0; i < 8; i++) {
        Serial.print(",");
        if (i < message.data_length_code) {
          Serial.print("0x");
          if (message.data[i] < 16) Serial.print("0");
          Serial.print(message.data[i], HEX);
        }
      }
      
      Serial.print(",");
      Serial.print(message.extd ? "true" : "false");
    }
    
    // Decode based on documented F150 CAN messages
    switch (message.identifier) {
      case PID_OAT: // Outside Air Temperature
        if (message.data_length_code >= 8) {
          updateOAT(decodeOAT(message.data[6], message.data[7]));
        }
        break;

      case PID_VEHICLE_SPEED: // Vehicle Speed
        if (message.data_length_code >= 2) {
          float mph = decodeSpeedMph(message.data[0], message.data[1]);
          if (mph <= OAT_MOVING_MPH) {
            movingSince = 0;
          } else if (movingSince == 0) {
            movingSince = millis();
          }
        }
        break;
        
      case PID_HVAC_TEMP: // HVAC Temperature Settings
        if (message.data_length_code >= 4) {
          driverTempSet = decodeHVACTemp(message.data[0], message.data[1]);
          passengerTempSet = decodeHVACTemp(message.data[2], message.data[3]);
          
          // When HVAC is off (driver temp = 0x00,0x00), set fan to 0
          if (driverTempSet == -1) {
            fanSpeed = 0;
          }
        }
        break;
        
      case PID_HVAC_FAN: // Fan Speed
        if (message.data_length_code >= 4) {
          fanSpeed = decodeFanSpeed(message.data[3]);
        }
        break;
        
      case PID_LIGHTING: // Headlamp / high beam state
        if (message.data_length_code >= 1) {
          bool hb = (message.data[0] & HIGH_BEAM_MASK) != 0;
          if (hb && !highBeamOn) highBeamSince = millis();
          highBeamOn = hb;
          lastLightingMsg = millis();
        }
        break;

      case PID_CONSOLE_LIGHTS: // Console Light Dimming
        if (message.data_length_code >= 4) {
          int level = decodeConsoleDim(message.data[3]);
          // Ignore unknown values so the screen never goes dark
          if (level > 0) {
            consoleDimLevel = level;
            setBacklightBrightness(consoleDimLevel);
          }
        }
        break;
    }
    
    // Complete CSV line with decoded values
    if (enableCSVLogging) {
      Serial.print(",");
      Serial.print(outsideTemp, 1);  // OAT with 1 decimal
      Serial.print(",");
      Serial.print(driverTempSet == -1 ? "BLANK" : String(driverTempSet));
      Serial.print(",");
      Serial.print(passengerTempSet == -1 ? "BLANK" : String(passengerTempSet));
      Serial.print(",");
      Serial.print(fanSpeed);
      Serial.print(",");
      Serial.println(consoleDimLevel);
    }
  }
}

// Simulate Data for Bench Testing
void simulateData() {
  static int testIndex = 0;
  static unsigned long lastCycle = 0;
  
  Serial.print("simulateData() called - testIndex: ");
  Serial.print(testIndex);
  Serial.print(", millis: ");
  Serial.print(millis());
  Serial.print(", lastCycle: ");
  Serial.println(lastCycle);
  
  // Initialize lastCycle on first run
  if (lastCycle == 0) {
    lastCycle = millis();
    Serial.println("Initialized lastCycle");
  }
  
  // Test extreme temperature values every 3 seconds
  if (millis() - lastCycle >= 3000) {
    // Cycle through test temperatures: negative, single digit, double digit, triple digit
    float testTemps[] = {-32.0, -5.0, 7.0, 22.0, 45.0, 72.0, 89.0, 104.0, 115.0};
    int numTests = sizeof(testTemps) / sizeof(testTemps[0]);
    
    outsideTemp = testTemps[testIndex % numTests];
    testIndex++;
    lastCycle = millis();
    
    Serial.print(">>> CHANGING OAT to: ");
    Serial.println(outsideTemp);
  }
  
  // Create simulation scenarios including blank values every 6 seconds
  unsigned long scenarioTime = millis() / 6000; // Switch scenarios every 6 seconds
  int scenario = scenarioTime % 5; // 5 different scenarios
  
  static int lastScenario = -1;
  if (scenario != lastScenario) {
    lastScenario = scenario;
    
    switch (scenario) {
      case 0: // Normal operation - both temps active
        driverTempSet = 72;
        passengerTempSet = 70;
        fanSpeed = 4;
        Serial.println("=== SCENARIO 0: Normal HVAC Operation ===");
        break;
        
      case 1: // HVAC Off - driver blank, fan 0
        driverTempSet = -1;  // Blank (HVAC off)
        passengerTempSet = 68;
        fanSpeed = 0;        // Fan off when HVAC off
        Serial.println("=== SCENARIO 1: HVAC System OFF (Driver blank, Fan 0) ===");
        break;
        
      case 2: // Passenger controls disabled
        driverTempSet = 74;
        passengerTempSet = -1; // Blank (passenger controls disabled)
        fanSpeed = 3;
        Serial.println("=== SCENARIO 2: Passenger Controls DISABLED (Pass blank) ===");
        break;
        
      case 3: // Both temps disabled
        driverTempSet = -1;   // Blank
        passengerTempSet = -1; // Blank
        fanSpeed = 0;         // Fan off
        Serial.println("=== SCENARIO 3: All HVAC Controls DISABLED (Both blank) ===");
        break;
        
      case 4: // Mix of extreme temps and blanks
        driverTempSet = 85;   // High temp
        passengerTempSet = -1; // Blank
        fanSpeed = 7;         // Max fan
        Serial.println("=== SCENARIO 4: Mixed State (Driver hot, Pass blank, Fan max) ===");
        break;
    }
    
    Serial.print("Driver: ");
    Serial.print(driverTempSet == -1 ? "BLANK" : String(driverTempSet));
    Serial.print(", Passenger: ");
    Serial.print(passengerTempSet == -1 ? "BLANK" : String(passengerTempSet));
    Serial.print(", Fan: ");
    Serial.println(fanSpeed);
  }
}

// Update Display with Smart Redrawing (only when data changes)
void updateDisplay() {
  // Only redraw cards that have changed data
  // Until a real reading lands, show the card with no number rather than the
  // 72.0 that outsideTemp is initialised to - inventing a temperature that
  // looks exactly like a measured one is worse than showing nothing.
  shownOAT = oatSeeded ? displayedOAT(outsideTemp, shownOAT, OAT_HYSTERESIS_F)
                       : OAT_DISPLAY_UNSET;
  if (shownOAT != drawnOAT) {
    drawnOAT = shownOAT;
    drawOATCard(OAT_X, OAT_Y, OAT_WIDTH, OAT_HEIGHT, shownOAT);
  }
  
  if (driverTempSet != prevDriverTempSet) {
    drawTempCard(DRIVER_X, BOTTOM_Y, CARD_WIDTH, CARD_HEIGHT, "DRIVER", driverTempSet);
    prevDriverTempSet = driverTempSet;
  }
  
  if (fanSpeed != prevFanSpeed) {
    drawFanCard(FAN_X, BOTTOM_Y, CARD_WIDTH, CARD_HEIGHT, fanSpeed);
    prevFanSpeed = fanSpeed;
  }
  
  if (passengerTempSet != prevPassengerTempSet) {
    drawTempCard(PASS_X, BOTTOM_Y, CARD_WIDTH, CARD_HEIGHT, "PASS", passengerTempSet);
    prevPassengerTempSet = passengerTempSet;
  }
  
  // Show simulation mode indicator (only once)
  static bool simModeShown = false;
  if (simulationMode && !simModeShown) {
    tft.setFont(&FreeSans9pt7b);
    tft.setTextColor(COLOR_WARNING);
    
    // Center the text horizontally and vertically on screen
    // Screen is 320x240, center vertically around y=120
    int16_t x1, y1;
    uint16_t w, h;
    tft.getTextBounds("SIMULATION MODE", 0, 0, &x1, &y1, &w, &h);
    int centerX = (320 - w) / 2;
    int centerY = 120;
    
    tft.setCursor(centerX, centerY);
    tft.print("SIMULATION MODE");
    simModeShown = true;
  } else if (!simulationMode && simModeShown) {
    // Clear sim mode text when not in simulation - clear center area
    tft.fillRect(80, 105, 160, 25, COLOR_BACKGROUND);
    simModeShown = false;
  }
  
  if (floodMode != prevFloodMode || floodLit != prevFloodLit) {
    drawFloodCard(FLOOD_X, FLOOD_Y, FLOOD_W, FLOOD_H, floodMode, floodLit);
    prevFloodMode = floodMode;
    prevFloodLit = floodLit;
  }
}

// Draw Outside Air Temperature Card
void drawOATCard(int x, int y, int w, int h, long temp) {
  // Card background
  tft.fillRoundRect(x, y, w, h, CARD_RADIUS, COLOR_CARD_BG);
  tft.drawRoundRect(x, y, w, h, CARD_RADIUS, COLOR_PRIMARY);
  
  // Center the label
  tft.setFont(LABEL_FONT);
  tft.setTextColor(COLOR_PRIMARY);
  int16_t x1, y1;
  uint16_t textW, textH;
  tft.getTextBounds("OAT", 0, 0, &x1, &y1, &textW, &textH);
  int centeredX = x + (w - textW) / 2;
  tft.setCursor(centeredX, y + LABEL_OFFSET_Y);
  tft.print("OAT");
  
  // Center the temperature value (larger font, no 'F' suffix).
  // OAT_DISPLAY_UNSET means no reading yet, so leave the value area empty -
  // same convention drawTempCard() uses for a disabled HVAC zone.
  if (temp != OAT_DISPLAY_UNSET) {
    tft.setFont(VALUE_FONT);
    tft.setTextColor(COLOR_TEXT);
    char tempStr[8];
    snprintf(tempStr, sizeof(tempStr), "%ld", temp);
    tft.getTextBounds(tempStr, 0, 0, &x1, &y1, &textW, &textH);
    centeredX = x + (w - textW) / 2;
    tft.setCursor(centeredX, y + OAT_VALUE_OFFSET_Y);
    tft.print(tempStr);
  }
}

// Draw Temperature Setting Card (Driver/Passenger)
void drawTempCard(int x, int y, int w, int h, const char* label, int temp) {
  // Card background
  tft.fillRoundRect(x, y, w, h, CARD_RADIUS, COLOR_CARD_BG);
  tft.drawRoundRect(x, y, w, h, CARD_RADIUS, COLOR_PRIMARY);
  
  // Center the label
  tft.setFont(LABEL_FONT);
  tft.setTextColor(COLOR_PRIMARY);
  int16_t x1, y1;
  uint16_t textW, textH;
  tft.getTextBounds(label, 0, 0, &x1, &y1, &textW, &textH);
  int centeredX = x + (w - textW) / 2;
  tft.setCursor(centeredX, y + LABEL_OFFSET_Y);
  tft.print(label);
  
  // Center the temperature value (larger font) - blank if temp is -1
  tft.setFont(VALUE_FONT);
  tft.setTextColor(COLOR_TEXT);
  
  if (temp == -1) {
    // Display nothing for disabled/off state
    // (Card background already drawn, so nothing to print)
  } else {
    char tempStr[4];
    sprintf(tempStr, "%d", temp);
    tft.getTextBounds(tempStr, 0, 0, &x1, &y1, &textW, &textH);
    centeredX = x + (w - textW) / 2;
    tft.setCursor(centeredX, y + VALUE_OFFSET_Y);
    tft.print(tempStr);
  }
}

// Draw Fan Speed Card (visual bars only)
void drawFanCard(int x, int y, int w, int h, int fanLevel) {
  // Card background
  tft.fillRoundRect(x, y, w, h, CARD_RADIUS, COLOR_CARD_BG);
  tft.drawRoundRect(x, y, w, h, CARD_RADIUS, COLOR_PRIMARY);
  
  // Center the label
  tft.setFont(LABEL_FONT);
  tft.setTextColor(COLOR_PRIMARY);
  int16_t x1, y1;
  uint16_t textW, textH;
  tft.getTextBounds("FAN", 0, 0, &x1, &y1, &textW, &textH);
  int centeredX = x + (w - textW) / 2;
  tft.setCursor(centeredX, y + LABEL_OFFSET_Y);
  tft.print("FAN");
  
  // Draw 7 fan bars (no numeric value) - centered for visual balance
  int barWidth = 8;
  int barSpacing = 11;
  int totalBarWidth = (7 * barWidth) + (6 * (barSpacing - barWidth));
  int startX = x + (w - totalBarWidth) / 2;
  int startY = y + 85;
  
  for (int i = 0; i < 7; i++) {
    int barX = startX + i * barSpacing;
    int barHeight = 6 + (i * 5);  // Taller bars with more height variation
    int barY = startY - barHeight;
    
    if (i < fanLevel) {
      // Active bar
      tft.fillRect(barX, barY, barWidth, barHeight, COLOR_PRIMARY);
    } else {
      // Inactive bar
      tft.fillRect(barX, barY, barWidth, barHeight, COLOR_TEXT);
    }
  }
}

// Decode Outside Air Temperature from CAN bytes 6-7 (see F150_OAT.md)
// Byte 6 is whole °C + 128, top 2 bits of byte 7 are quarter degrees
float decodeOAT(uint8_t byte6, uint8_t byte7) {
  int raw = (byte6 << 2) | (byte7 >> 6);
  float celsius = raw / 4.0 - 128;
  return (celsius * 1.8) + 32.0;
}

// Decode Vehicle Speed from CAN bytes 0-1 (see F150_SPEED.md)
// Big-endian, 0.01 km/h per bit, offset 10000 (= stopped)
float decodeSpeedMph(uint8_t byte0, uint8_t byte1) {
  int raw = (byte0 << 8) | byte1;
  float kph = (raw - 10000) / 100.0;
  return kph / 1.609;
}
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

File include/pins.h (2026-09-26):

#ifndef PINS_H
#define PINS_H

// Define pins for the ILI9341 display
#define TFT_CS   45
#define TFT_RST  0 
#define TFT_DC   35 
#define TFT_MOSI 36
#define TFT_CLK  37
#define TFT_LED  38
#define TFT_MISO 39

#define TOUCH_CLK  40
#define TOUCH_CS 41
#define TOUCH_DIN 42
#define TOUCH_DO 2
#define TOUCH_IRQ  1

// CAN Bus pins
#define CAN_RX_PIN 48
#define CAN_TX_PIN 47

// Status LED
#define STATUS_LED_PIN 15

// Flood light control - drives 2N2222A base via 220R, switches relay coil
// Board: pcb/F150_light_ctl. Not 19/20 (native USB), not 0/3/45/46 (strapping).
#define FLOOD_PIN 13

// Colors
#define COLOR_BACKGROUND 0x0841
#define COLOR_CARD_BG    0x2124
#define COLOR_PRIMARY    0x07FF
#define COLOR_TEXT       0xFFFF
#define COLOR_SUCCESS    0x07E0
#define COLOR_WARNING    0xFFE0

#endif // PINS_H

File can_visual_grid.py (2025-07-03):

#!/usr/bin/env python3
"""
CAN Bus Visual Grid Monitor with ASCII/HEX Toggle
Real-time visual grid showing all PIDs and bytes with color-coded changes
Toggle between HEX and ASCII display to find Ford's ASCII-encoded values
Click on cells to select up to 2 for combined analysis
"""

import pygame
import serial
import threading
import time
import argparse
import sys
from collections import defaultdict

class CANVisualGrid:
    def __init__(self, port, baud_rate=115200):
        self.port = port
        self.baud_rate = baud_rate
        self.serial = None
        self.running = False
        
        # Pygame setup - use more screen space
        pygame.init()
        self.WINDOW_WIDTH = 1600  # Increased width
        self.WINDOW_HEIGHT = 900
        self.screen = pygame.display.set_mode((self.WINDOW_WIDTH, self.WINDOW_HEIGHT))
        pygame.display.set_caption("🌡️ F150 CAN Bus Visual Monitor - ASCII/HEX Explorer")
        
        # Grid settings - bigger cells
        self.CELL_WIDTH = 80  # Increased from 60
        self.CELL_HEIGHT = 24  # Increased from 20
        self.HEADER_HEIGHT = 40
        self.PID_COLUMN_WIDTH = 100  # Increased from 80
        self.START_X = self.PID_COLUMN_WIDTH
        self.START_Y = self.HEADER_HEIGHT
        
        # Display mode toggle
        self.display_mode = "HEX"  # "HEX" or "ASCII"
        
        # Colors
        self.BLACK = (0, 0, 0)
        self.WHITE = (255, 255, 255)
        self.GREEN = (0, 255, 0)
        self.BRIGHT_GREEN = (50, 255, 50)
        self.YELLOW = (255, 255, 0)
        self.BLUE = (100, 150, 255)
        self.GRAY = (128, 128, 128)
        self.DARK_GRAY = (64, 64, 64)
        self.RED = (255, 100, 100)
        self.LIGHT_BLUE = (173, 216, 230)
        self.ORANGE = (255, 165, 0)
        self.PURPLE = (255, 0, 255)
        self.CYAN = (0, 255, 255)
        self.LIGHT_GREEN = (144, 238, 144)
        
        # Fonts - bigger fonts for better readability
        self.small_font = pygame.font.Font(None, 16)
        self.tiny_font = pygame.font.Font(None, 14)
        self.header_font = pygame.font.Font(None, 18)
        self.info_font = pygame.font.Font(None, 16)
        self.big_font = pygame.font.Font(None, 20)
        
        # Data storage
        self.pid_list = []  # Ordered list of PIDs as they appear
        self.current_values = defaultdict(lambda: [0] * 8)  # [pid] = [byte0, byte1, ..., byte7]
        self.change_times = defaultdict(lambda: [0] * 8)    # [pid] = [time_byte0_changed, ...]
        self.total_messages = 0
        self.messages_per_second = 0
        self.last_fps_time = time.time()
        self.last_message_count = 0
        
        # Scroll offset for when we have too many PIDs
        self.scroll_offset = 0
        self.max_visible_rows = (self.WINDOW_HEIGHT - self.START_Y - 150) // self.CELL_HEIGHT  # Leave more space for info panel
        
        # Multi-cell inspector - can select up to 2 cells
        self.selected_cells = []  # List of (pid, byte_index) tuples, max 2
        self.info_panel_height = 120  # Increased height for more info
        
        # Temperature calibration logging
        self.calibration_mode = False
        self.calibration_data = []  # List of (actual_temp, combined_value, timestamp)
        
    def connect(self):
        """Connect to serial port"""
        try:
            self.serial = serial.Serial(self.port, self.baud_rate, timeout=0.1)
            print(f"✅ Connected to {self.port}")
            return True
        except Exception as e:
            print(f"❌ Connection failed: {e}")
            return False
    
    def handle_temperature_input(self):
        """Handle temperature input from user during calibration"""
        try:
            # Get current combined value
            if len(self.selected_cells) >= 2:
                pid1, byte1_idx = self.selected_cells[0]
                pid2, byte2_idx = self.selected_cells[1]
                byte0_val = self.current_values[pid1][byte1_idx]
                byte1_val = self.current_values[pid2][byte2_idx]
                combined = (byte0_val << 8) | byte1_val
                
                # This would need to be implemented with a proper input dialog
                # For now, just show what we would do
                print(f"🌡️ Current CAN value: {combined} - Use console input for actual temperature")
        except Exception as e:
            print(f"Error getting temperature input: {e}")
    
    def calculate_temperature_formula(self):
        """Calculate linear regression formula from calibration data"""
        if len(self.calibration_data) < 2:
            return
        
        # Extract x (CAN values) and y (temperatures)
        x_vals = [point[1] for point in self.calibration_data]  # CAN values
        y_vals = [point[0] for point in self.calibration_data]  # Actual temps
        
        # Simple linear regression: y = mx + b
        n = len(self.calibration_data)
        sum_x = sum(x_vals)
        sum_y = sum(y_vals)
        sum_xy = sum(x * y for x, y in zip(x_vals, y_vals))
        sum_x2 = sum(x * x for x in x_vals)
        
        # Calculate slope (m) and intercept (b)
        m = (n * sum_xy - sum_x * sum_y) / (n * sum_x2 - sum_x * sum_x)
        b = (sum_y - m * sum_x) / n
        
        print(f"\n🧮 CALCULATED FORMULA:")
        print(f"temperature_f = {m:.6f} * combined_value + {b:.2f}")
        print(f"📐 Or: temperature_f = (combined_value * {m:.6f}) + {b:.2f}")
        
        # Test the formula with collected data
        print(f"\n🧪 FORMULA TEST:")
        print("Actual | Predicted | Error")
        print("-" * 30)
        for actual_temp, can_val, _ in self.calibration_data:
            predicted = m * can_val + b
            error = abs(actual_temp - predicted)
            print(f"{actual_temp:6.1f} | {predicted:9.1f} | {error:5.1f}")
        
        # Calculate average error
        avg_error = sum(abs(temp - (m * can_val + b)) for temp, can_val, _ in self.calibration_data) / n
        print(f"\n📊 Average error: {avg_error:.2f}°F")
    
    def parse_can_message(self, line):
        """Parse CAN message from CSV format"""
        if line.startswith('#') or not line.strip():
            return None
        
        try:
            parts = line.split(',')
            if len(parts) < 8:
                return None
            
            can_id = parts[2].strip()
            if not can_id.startswith('0x'):
                return None
            
            # Parse all 8 bytes
            byte_values = []
            for i in range(8):
                if 4 + i < len(parts):
                    hex_val = parts[4 + i].strip()
                    if hex_val and hex_val.startswith('0x'):
                        byte_values.append(int(hex_val, 16))
                    else:
                        byte_values.append(0)
                else:
                    byte_values.append(0)
            
            return (can_id, byte_values)
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

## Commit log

2025-07-08 added images and stl files
    [Arm.stl, PartPlate.stl, Screen_back.stl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]
2026-09-19 fix(backlight): keep display lit in night mode (#2)
    Byte 3 of 0x3B3 is one brightness scale: night mode sends 0x01-0x0C,
    day mode 0x0D-0x12. Only the day range was mapped, so night values
    decoded to level 0 and turned the backlight off.
    - Decode byte 3 directly as level 1-18; ignore unknown values
    - Separate PWM ranges for night (15-170) and day (60-255)
    - Scale the 6-dot indicator to 18 levels
    - Route Serial to the S3 native USB port
    - Document night-mode values
    Refs #1
    [main.cpp]
2026-09-19 fix(oat): dampen OAT at low speed to hide engine heat soak (#4)
    The OAT sensor heat-soaks when slow or stopped (captured +5°F in 10 s
    after stopping). The truck doesn't broadcast a filtered value, so damp
    it here: show raw OAT only after >20 mph for 30 s, otherwise the display
    can only drop.
    - Decode vehicle speed from 0x423 bytes 0-1
    - Use byte 7 of 0x3C4 for 0.25°C resolution
    - Redraw OAT card only when the rounded value changes
    - Document speed and OAT damping
    Refs #3
    [main.cpp]
2026-09-26 feat(flood): LED light bar control with high beam arming (#6)
    * feat(flood): add GPIO 13 control and bring-up harness
    Adds FLOOD_PIN on GPIO 13, driving a 2N2222A/MMBT2222A base through 220R to
    switch the light bar relay coil. Avoids GPIO 19/20 (native USB D-/D+, used for
    flashing and logging) and the S3 strapping pins.
    Also adds a floodtest environment that builds only src/test_flood.cpp, giving a
    way to toggle the relay over serial without the UI. Kept because the
    touchscreen is currently the only other control path.
    * feat(flood): add touchscreen button with high beam arming
    Wires up the XPT2046 touch controller, unus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
    [F150_light_ctl.kicad_pcb, F150_light_ctl.kicad_sch]
2026-09-26 fix(oat): add display hysteresis to stop the reading flickering (#8)
    * fix(oat): add display hysteresis to stop the reading flickering
    The shown degree came straight from lround() on every update, with no dead
    band, so a reading parked near a half-degree boundary crossed it on a single
    0.45 F quantisation step and the display alternated between two numbers
    indefinitely. Only visible at speed, since below OAT_MOVING_MPH updateOAT()
    ratchets downward and cannot oscillate.
    The displayed value now moves only once the reading clears it by 0.7 F, more
    than one sensor step. Shown 72 becomes 73 at 72.7 and 71 at 71.3, so genuine
    movement still tracks while dither does not.
    Logic lives in include/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
    [main.cpp]
2026-09-26 fix(touch): correct Y calibration so button presses register (#10)
    * fix(touch): correct Y calibration so button presses register
    TOUCH_RAW_MAXY was 2830, but the top of this panel actually reads ~3402. Every
    press near the top of the screen therefore computed a negative screen position
    and clamped to sy=0, one pixel below the FLOOD button's y=10 edge, so it always
    missed. Measured by pressing the extreme top and bottom edges: rawY 858 at the
    bottom, 3402 at the top. Real button presses now map to sy 20-39, comfortably
    inside the 10-90 band.
    The original range came from a capture that never reached the top of the
    screen, so the upper end was extrapolated and badly short.
    Also switches the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
    [main.cpp, test_flood.cpp]
